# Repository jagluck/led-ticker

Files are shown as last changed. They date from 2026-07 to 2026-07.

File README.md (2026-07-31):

# LED Ticker

Desk sign + ambient ticker built on an ESP32-S3 and a 4-in-1 MAX7219 LED matrix. Rotates stocks, weather, news, and a clock; flips to a steady sign or a countdown timer on demand. Wi-Fi only feeds the live data; the sign and timer run fully offline.

<p align="center">
  <picture>
    <source media="(prefers-color-scheme: dark)" srcset="assets/device-sketch-dark.png">
    Line-art illustration of the LED Ticker — a 4-in-1 LED matrix in a bracket, wired to an ESP32-S3 board
  </picture>
</p>

## Features

- **Sign mode** — one-tap status text ("BUSY", "FOCUS", "DND") that overrides the ambient rotation, with an optional auto-clear timer. Or run a **countdown timer** (1–99 min): a live `MM:SS`, an end animation, then back to ambient.
- **Live data** — stock quotes (Finnhub), multi-location weather (MET Norway), and news.
- **12-hour clock** — steady `HH:MM` when shown alone, scrolls `H:MM AM/PM` when mixed in.
- **Display on/off** — blank the matrix and pause fetches without losing the saved ambient mode.
- **Adjustable brightness & scroll speed** — set from the mobile app or CLI, applied live and persisted on the device.
- **Companion mobile app** — multi-device switcher, preset chip grid, and per-category display toggles, on [iOS](https://apps.apple.com/app/id6772027776) and [Android](https://github.com/ssayala/led-ticker-android).
- **Configured entirely over BLE** — no build-time secrets; WiFi, Finnhub key, tickers, locations, mode, timezone, and active sign all set wirelessly and persisted.
- **PIN-gated BLE** — every write requires a 6-digit PIN, generated on first boot and rotated on factory reset.
- **Factory reset** — hold the BOOT button for 10 s to wipe all settings, forget every BLE bond, and reboot into setup mode with a fresh PIN.

## Hardware

A [Freenove ESP32-S3-WROOM (FNK0099)](https://store.freenove.com/products/fnk0099) and a 4-in-1 MAX7219 LED matrix (the common FC16 type, sold by many vendors). Wiring, porting notes, and pin config are in [Getting started](GETTING_STARTED.md#hardware--wiring). The repo includes a [custom PCB](hardware/pcb/README.md) and a [3D-printable frame](hardware/case/).

## Build & flash

1. Install [PlatformIO](https://platformio.org/).
2. Clone the repo: `git clone https://github.com/ssayala/led-ticker && cd led-ticker`.
3. Build and upload from the repo root: `pio run -d firmware -t upload`, then press the board's reset button.
4. First boot scrolls the BLE name + a 6-digit PIN — note it; you'll need it on every client.

No toolchain? Flash released firmware straight from a browser at **[ledticker.app/flash](https://ledticker.app/flash)**.

Provision from the mobile app or the CLI.

## Documentation

- **[Getting started](GETTING_STARTED.md)** — build, flash, first-boot pairing, and `config.h` tuning.
- **[Python client (`led_ticker`)](tools/README.md)** — `pip`-installable library (`from led_ticker import LedTicker`) and the `uv`-based `led.py` CLI, for driving the device or building your own tools.
- **[BLE protocol](BLE_PROTOCOL.md)** — UUIDs, payloads, and semantics for custom clients.
- **[Firmware guide](firmware/FIRMWARE_GUIDE.md)** — firmware internals: dual-core model, display state machine, and how to extend it.
- **[Custom PCB](hardware/pcb/README.md)** — board sources, render, and ordering.
- **[3D-printed frame](hardware/case/)** — printable parts (top/bottom strips or a single bracket) that hold the matrix and PCB together.
- **Companion mobile app** — [iOS](https://apps.apple.com/app/id6772027776) (App Store) and [Android](https://github.com/ssayala/led-ticker-android) (open source).

## License

Open and permissive — free to use, build, modify, share, and sell, including commercially, with attribution.

- **Firmware** — [Apache-2.0](LICENSE).
- **Hardware design files** in [`hardware/`](hardware/) (PCB, mechanical, frame STLs) — [CC BY 4.0](hardware/LICENSE).
- **Python client** in [`tools/`](tools/) (the `led_ticker` package & `led` CLI) — [Apache-2.0](tools/LICENSE).

Attribution is required by these licenses — please keep the credit; see [NOTICE](NOTICE).

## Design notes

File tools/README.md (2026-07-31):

# `led_ticker` — Python library & CLI for the LED Ticker

`led_ticker` speaks the same BLE service as the companion mobile app, so you can drive the
device — or build your own tools — from any machine with Bluetooth. The device
advertises as `LED-Ticker-XXXX`.

## Install

```bash
pip install led-ticker      # or: uv add led-ticker
```

This installs the importable `led_ticker` package and the `led` command.

## Running the CLI

How you invoke the CLI depends on how it was installed:

```bash
led <cmd>                   # pip install into an active venv → on PATH
uv run led <cmd>            # uv add led-ticker → script is in .venv/bin, not on PATH
uv run tools/led.py <cmd>   # from a checkout of this repo → uses ./src directly
```

The examples below use `led`; prefix with `uv run` if you installed via `uv add`.

## Library

```python
from led_ticker import LedTicker, scan

# Scan for available devices (returns DeviceInfo with name, address, rssi):
for d in scan():
    print(d.name, d.address, d.rssi)

# Reuse one connection for several operations:
with LedTicker(pin="482913") as d:
    d.set_tickers(["AAPL", "MSFT"])
    d.set_status("BUSY", minutes=30)
    print(d.get_version())          # -> "0.7.0"
    s = d.get_status()              # -> Status(text="BUSY", seconds=1800)

# Or a one-shot for a single call (opens and closes its own connection):
import led_ticker
led_ticker.set_mode(["stocks", "weather"])
```

`LedTicker(select=None, address=None, name_prefix="LED-Ticker", scan_timeout=4.0, timeout=15.0, pin=None)`.
By default the first `LED-Ticker-*` in range is used; if several are in range it raises
`AmbiguousDeviceError` (whose `.candidates` is a list of `DeviceInfo`). Pass `select=` to
choose a specific unit (see [Selecting a device](#selecting-a-device)), or `address=` to
target a known address directly (skips the scan). Methods raise
`ValidationError`, `AuthError`, `DeviceNotFoundError`, `AmbiguousDeviceError`, or
`ProtocolError` (all subclasses of `LedTickerError`).

`pin=None` does **not** mean "no auth" — it falls back to the same resolution the
CLI uses (`LED_TICKER_PIN` env var, then the `~/.config/led-ticker/pin` cache),
so a saved PIN is picked up automatically. Pass `pin="482913"` to override.

## Selecting a device

With more than one LED-Ticker in range, list them and target one explicitly:

```bash
led devices                 # list units: name, address, signal
led --device A1B2 status "BUSY" 30   # target by name suffix
```

`--device` matches a unit by its name suffix (the `XXXX` in `LED-Ticker-XXXX`),
its full name, or its Bluetooth address. If you run a command with several units
in range and no `--device`, an interactive terminal prompts you to choose; in a
script (no TTY) it lists the candidates and exits non-zero so you can re-run with
`--device`.

## CLI

```bash
# Sign mode
led status "BUSY" 30      # show for 30 min, then auto-clear
led status "ON AIR"       # indefinite
led status clear

# Timer mode (countdown sign — random animation at zero, then resumes ambient)
led timer 10              # 10-minute countdown
led timer cancel

# Ambient mode (subset of stocks/weather/news/clock, 'all', or 'none' for sign-only)
led mode stocks weather
led mode clock
led mode all
led mode none

# Power (volatile — power cycle returns to on)
led power on
led power off

# Display settings (persisted on the device)
led display                  # show current brightness + scroll speed
led display brightness 8     # brightness 0-15
led display speed 50         # scroll ms/step 20-500 (lower = faster)
led display 8 50             # both at once

# Timezone (persisted; POSIX TZ string — companion apps have a friendly picker)
led timezone                              # show current
led timezone "EST5EDT,M3.2.0,M11.1.0"     # US Eastern

# Data
led tickers AAPL TSLA NVDA SPY
led locations "47.61,-122.33,Seattle"   # lat,lon,label (look up coords online)
led apikey your-finnhub-key
led wifi My Network Name password

# Inspect
led get version           # firmware version on the device
led get wifi|apikey|tickers|status|locations|mode|power|display|timezone|version  # read other settings

# Auth
led pin 482913            # save the device's PIN locally (~/.config/led-ticker/pin)
led pin clear             # forget the saved PIN
led --pin 482913 status "BUSY" 30   # use a PIN for one call, without saving it
led pin-enforce on        # device: require PIN for writes (default after a fresh flash)
led pin-enforce off       # device: stop requiring PIN (escape hatch)

# Maintenance
led reload                # force stock/weather/news refresh
led reset                 # wipe NVS, rotate PIN, revert to config.h defaults
```

Save once, every platform: run `led pin <6 digits>` a single time and it's replayed on each connection automatically — no per-command `--pin`, on Linux, Windows, and macOS alike. (Companion mobile apps instead use OS-level Bluetooth *bonding* — the phone prompts for the PIN once and the OS remembers it; the CLI never bonds.)

PIN resolution: every command (and the library) looks for the PIN in this order — `--pin XXXXXX` flag → `LED_TICKER_PIN` env var → the saved cache file (`~/.config/led-ticker/pin`). The env var suits CI or anyone who'd rather not write the PIN to disk. If none is found and the device has enforcement on, writes fail with a clear `AuthError`.

Stale-PIN safety: every write probes the device after sending the PIN and exits with a clear error if the PIN was rotated by a factory reset — a write never fails silently because of an out-of-date local PIN.

## License

[Apache-2.0](LICENSE) — free to use, including commercially, with attribution. (The firmware in the parent repo is also Apache-2.0; the hardware design files are CC BY 4.0 — see the [repo root](https://github.com/ssayala/led-ticker).)

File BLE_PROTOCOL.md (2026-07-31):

# BLE Protocol

The device advertises as `LED-Ticker-XXXX`, where `XXXX` is the low 2 bytes of the chip MAC (so multiple boards on the same bench are distinguishable). All characteristics except `Command` are read/write — reads return current state. `Command` is write-only.

Writes are deferred: the BLE callback copies the payload and a main-loop pass applies it. Writes return immediately even when the change triggers network, display, or NVS work — clients should not assume the effect is observable synchronously.

## Service

`4fafc201-1fb5-459e-8fcc-c5c9c331914b`

## Characteristics

| Characteristic | UUID | Access |
|---|---|---|
| Tickers | `beb5483e-36e1-4688-b7f5-ea07361b26a8` | read/write |
| Mode | `beb5483e-36e1-4688-b7f5-ea07361b26a9` | read/write |
| Command | `beb5483e-36e1-4688-b7f5-ea07361b26ab` | write |
| WiFi | `beb5483e-36e1-4688-b7f5-ea07361b26ac` | read/write (read returns SSID only) |
| API Key | `beb5483e-36e1-4688-b7f5-ea07361b26ad` | read/write |
| Locations | `beb5483e-36e1-4688-b7f5-ea07361b26ae` | read/write |
| Status | `beb5483e-36e1-4688-b7f5-ea07361b26af` | read/write |
| Version | `beb5483e-36e1-4688-b7f5-ea07361b26b0` | read |
| Power | `beb5483e-36e1-4688-b7f5-ea07361b26b1` | read/write |
| Auth | `beb5483e-36e1-4688-b7f5-ea07361b26b2` | write |
| Display | `beb5483e-36e1-4688-b7f5-ea07361b26b3` | read/write |
| Timezone | `beb5483e-36e1-4688-b7f5-ea07361b26b4` | read/write |

UUID `...26aa` was once a "Messages" characteristic and is **not** registered in the current firmware. Reads against it fail at the GATT layer. Don't reuse the UUID.

## Payload formats

### Tickers
Comma-separated symbols. Example: `AAPL,MSFT,GOOGL`. Up to 10 symbols, 15 chars each.

### Mode
A single category (`stocks`, `weather`, `news`, `clock`), `all`, `none`, or a comma-separated subset (e.g. `stocks,weather`). Persisted to NVS. The device round-robins through enabled categories. When `clock` is the *only* enabled category the display shows a steady 24-hour `HH:MM`; mixed with others it scrolls the same `HH:MM`.

`none` is sign-only mode: no ambient rotation; between signs the display sits on the dim bouncing-pixel idle state. Reads return `"none"`.

Requesting a subset whose prereqs are missing (e.g. stocks without WiFi/API key) diverts the display to **setup mode** — the device scrolls its BLE name until the missing pieces are configured (or the 60s inactivity timer falls into the chosen mode).

The Status characteristic is **orthogonal** to the mode mask: an active sign overrides ambient until cleared or expired. When a sign clears on a device whose prereqs are still unmet, the display drops to **idle** (a single dim bouncing pixel) rather than the setup-name scroll — the user already found the device, so re-scrolling the name would be noise. Mode reads still return the configured mask; idle is an internal display state, not a settable mode.

### Status
Write `text|N` to set, empty payload to clear.

- `N` is unsigned integer *seconds* until auto-clear; `N=0` means indefinite (until cleared).
- Text up to 96 bytes. Short text (≤4 chars) displays steady; longer text scrolls.
- Reads return `text|M` where `M` is seconds remaining (`0` if indefinite), or empty string when no status is active.
- **RAM-only** — a power cycle clears any active sign and resumes ambient.
- Timed signs use the MCU's monotonic `millis()` counter, so they work without WiFi/NTP.
- There is no preset library on the device; preset chips are managed client-side (e.g. a companion app's local list).

### Locations
Pipe-separated `lat,lon,label` triplets — `47.61,-122.33,Seattle|47.67,-122.12,Redmond`. Up to 5 entries, 47 chars each. The **client** geocodes place names to coordinates — companion apps use the phone's location APIs; CLI users look up `lat`/`lon` themselves — so the device never contacts a geocoding service. `lat`/`lon` are decimal degrees; `label` is the text shown on the matrix (≤23 chars, may contain commas — only the first two commas are delimiters). Malformed or out-of-range entries are skipped.

### Command
Write-only.
- `reload` — force an immediate stock + weather + news fetch.
- `reset` — factory reset: wipe NVS and reboot. The wipe is deferred behind a 9-second single-digit countdown on the matrix (the BOOT-button hold shows the same digits) — **power-cycle the device during the countdown to abort**, since nothing is written until it finishes. Reverts to `config.h` defaults (clears WiFi, API key, any active sign, and the PIN — full reconfiguration needed after; a new PIN is generated and shown in setup mode). The connection drops when the device restarts; the write is ACKed first.
- `pin-enforce on` / `pin-enforce off` — toggle the Auth PIN gate on writes. **On is the default** on a fresh flash.
- `timer <minutes>` — countdown sign (1–99 whole minutes): live `MM:SS`, then a randomly-chosen end animation (fireworks / sonar pulse / sparkle), then ambient resumes. No cooldown — feels immediate, like a sign. Mutually exclusive with the text sign: each cancels the other. RAM-only and fire-and-forget — reads don't report timer state, so clients track the countdown locally.
- `timer cancel` — stop a running countdown and resume ambient immediately.

### WiFi
`SSID|password` — split on the first `|`. Passwords may contain `|`; SSIDs may not. Updates credentials, saves to NVS, reconnects immediately. Reads return the SSID only.

### API Key
Plain string — Finnhub API key. Saved to NVS, triggers an immediate stock fetch.

### Version
Read-only. Returns the firmware version (e.g. `0.1.0`) — the `FW_VERSION` define in `firmware/src/version.h`. Older firmwares won't expose this characteristic; treat its absence as "unknown / pre-0.1.0".

### Power
Write `"on"` or `"off"` (case-insensitive, whitespace-tolerant) to toggle the display. Reads return current state. Unknown payloads are ignored (no GATT error; state unchanged).

- Power is a third orthogonal layer alongside Mode and Status: `"off"` makes the device visually inert (matrix dark, NeoPixel dark, signs suppressed, periodic fetches paused — explicit-refresh writes like ticker updates or `reload` still apply) without touching `enabledMask` or any persisted state. `"on"` resumes the saved ambient mode and triggers an immediate fetch.
- Sign writes while off are accepted and stored but not rendered; on wake, an un-expired sign reappears. Timed signs keep counting down while off.
- **RAM-only — not persisted.** A power cycle returns the device to `"on"`. Older firmwares won't expose it.

### Display
Write `brightness|scroll_ms` — e.g. `4|70`. Brightness is the MAX7219 intensity, 0–15; scroll speed is ms per scroll step, 20–500 (lower = faster). Out-of-range values are clamped, non-numeric or separator-less payloads are ignored. Reads return current values in the same format.

- Persisted to NVS; survives reboot. Factory reset reverts both to the `config.h` defaults (brightness 2, scroll 70).
- Applied immediately — brightness everywhere, scroll speed including an in-flight scroll. Setup mode keeps its own fixed slower scroll until configuration completes.
- Older firmwares won't expose this characteristic.

### Timezone
Write a POSIX TZ string — e.g. `PST8PDT,M3.2.0,M11.1.0` (US Pacific) or `IST-5:30` (India). Up to 63 bytes; must start with a letter. Reads return the current string.

- Persisted to NVS; applied to the display clock immediately. Factory reset reverts to the `config.h` default (US Pacific).
- NYSE market hours are computed in Eastern Time from UTC, independent of this setting.
- Companion apps map a human-readable timezone picker to these strings; the raw format is only needed from the CLI.
- Older firmwares won't expose this characteristic.

### Auth

A BLE connection is "authenticated" (allowed to write to non-Auth characteristics) once either of these happens:

1. **Bonded link:** The device advertises passkey-entry pairing (`bond=true, MITM=true, SC=true`, IO cap `DISPLAY_ONLY`) and asks the central to pair on every fresh connection. The phone shows its native pairing dialog, and the user types the 6-digit PIN from the LED matrix.
2. **PIN write:** The client writes the 6-digit PIN to the Auth characteristic (`…26b2`, write-only). On match, the connection is authenticated for its lifetime. This is the fallback for clients that decline pairing (e.g., Python CLI on Linux).

Reads always work — auth gates writes only.

> [!NOTE]
> Implementation details regarding connection slots (`AuthSlot`), rate-limiting (5 wrong PINs → 5-second silent lockout), concurrent connection limits, and NVS PIN persistence can be found in the [Firmware Guide: Security & Auth](firmware/FIRMWARE_GUIDE.md#7-security-authentication--rate-limiting).

## Cooldown

Writes that trigger upstream network activity — Tickers, Locations, `Command=reload`, `Command=reset` — share a 10-second cooldown to prevent hammering the APIs if a client retries. Other writes (WiFi, API Key, Mode, Status, Power, Display, Timezone, Auth, `Command=pin-enforce`) are not gated.

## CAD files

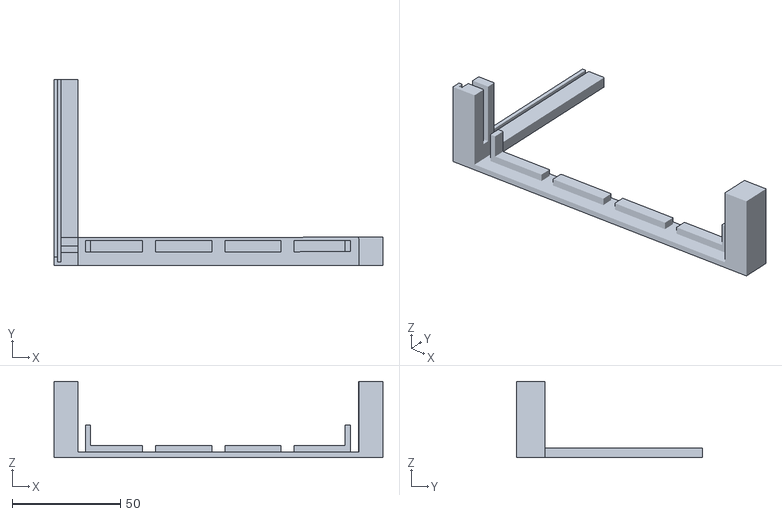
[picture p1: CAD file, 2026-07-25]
hardware/case/top-strip.stl
152.1 x 86.0 x 35.2

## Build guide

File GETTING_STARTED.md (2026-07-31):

# Getting started

Build, flash, and configure an LED Ticker. For what it is and what it does, see the [main README](README.md).

## Hardware & wiring

The firmware targets one specific board; the custom PCB is sized for the same module (see [`hardware/pcb/`](hardware/pcb/README.md)).

| Component | Part |
|---|---|
| MCU board | [**Freenove ESP32-S3-WROOM (FNK0099)**](https://store.freenove.com/products/fnk0099) — onboard NeoPixel on GPIO 48, native USB-CDC |
| Display | 4-in-1 MAX7219 LED matrix (FC16 type, any vendor) |

### Wiring (matches the PCB)

| Matrix Pin | ESP32-S3 GPIO |
|---|---|
| VCC | 5V |
| GND | GND |
| DIN | 6 (MOSI) |
| CLK | 4 (SCK) |
| CS | 5 |

Onboard RGB LED (GPIO 48) lights blue during network fetches. The Freenove board's **BOOT button (GPIO 0)** doubles as the factory-reset trigger — hold for 10 s during normal runtime.

**Using a different ESP32-S3 board?** Edit `DIN_PIN` / `CLK_PIN` / `CS_PIN` / `RGB_LED_PIN` in `firmware/src/config.h`. The PCB has no flexibility — it's footprint-specific to the FNK0099.

## Build & flash

1. Install [PlatformIO](https://platformio.org/).
2. Optionally edit defaults in `firmware/src/config.h` — seed tickers/locations (first-boot NVS seed) and the tunables under [Configuration](#configuration) below.
3. Build and upload from the repo root: `pio run -d firmware -t upload`. Press the physical reset button after flashing.
4. On first boot the display scrolls the BLE device name **and a 6-digit PIN** (e.g. `LED-Ticker-AB12  PIN 482 913`). Note the PIN — you'll need it on every client.

> **No toolchain?** Released firmware can be flashed straight from a browser over USB at **[ledticker.app/flash](https://ledticker.app/flash)** — Chrome or Edge on a desktop, no PlatformIO required.

## First-boot pairing

- **Phone app:** open the app, tap the device. The phone pops a system pairing dialog — type the PIN. Bonded. Future reconnects skip the dialog.
- **CLI:** save the PIN once; future calls auto-include it (see the [CLI tool](tools/README.md)):
  ```
  uv run tools/led.py pin 482913
  uv run tools/led.py wifi My Network Name password123
  uv run tools/led.py apikey your-finnhub-key
  ```
  The last arg to `wifi` is always the password — everything before it is the SSID, so spaces work naturally. To avoid saving the PIN to disk, pass `--pin 482913` per command or set `LED_TICKER_PIN=482913` in the environment instead.

If you ever forget the PIN, read it off the serial monitor (`pio device monitor -d firmware`) at boot, or factory-reset to rotate it.

## Configuration

**User tunables — `firmware/src/config.h`:**

| Define | Default | Description |
|---|---|---|
| `SCROLL_SPEED` | 70 | ms per scroll step (lower = faster) |
| `SETUP_SCROLL_SPEED` | 100 | Slower scroll used only in setup mode so the BLE name + PIN are easy to read. Reverts to `SCROLL_SPEED` once setup completes. |
| `DISPLAY_INTENSITY` | 2 | LED brightness, 0–15. Idle mode (post-sign with no ambient data) dims to 0 regardless of this setting. |
| `TIMEZONE` | `PST8PDT,M3.2.0,M11.1.0` | POSIX TZ string |
| `NTP_SERVER_1` / `NTP_SERVER_2` | `time.google.com` / `time.cloudflare.com` | NTP hosts (anycast, no vendor-zone registration) |
| `FETCH_INTERVAL_MS` | 5 min | Stock + weather + news refresh interval |

**Hardware pins — `firmware/src/config.h`:** `HARDWARE_TYPE`, `MAX_DEVICES` (4), `DIN_PIN`/`CLK_PIN`/`CS_PIN` (6/4/5), `RGB_LED_PIN` (48), `BUTTON_PIN` (0). Edit these when porting to a different board — see [Hardware & wiring](#hardware--wiring) above.

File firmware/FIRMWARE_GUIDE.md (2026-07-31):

# Firmware Guide

How the ESP32-S3 LED Ticker firmware works, at a high level. The detail lives in the code — `main.cpp` is structured and commented — and the Bluetooth wire format is in [`BLE_PROTOCOL.md`](../BLE_PROTOCOL.md). This is the map, not the territory.

## What it does

Drives a 4-panel LED matrix with two independent layers:

- **Ambient rotation** — cycles through whatever's enabled: stock quotes, weather, news, and a clock.
- **Override** — a text sign or a countdown timer that takes over the whole panel until it clears, then ambient resumes.

If it hasn't been configured yet (no WiFi or API key), it drops into a **setup** mode instead.

## Two cores

Network calls take seconds; the scrolling has to stay smooth. So the work is split across the ESP32's two cores:

- **Core 0** fetches data over WiFi and runs the Bluetooth stack.
- **Core 1** does everything you see — drives the matrix, runs the display modes, watches the button, and polls the USB serial console.

They hand off through shared buffers protected by a mutex. Control writes never draw or touch the network directly: a Bluetooth callback (Core 0) or the serial console poll (Core 1) just stashes the incoming value, and the Core 1 loop picks it up and applies it on its next pass. That keeps the radio and the display from stepping on each other.

```mermaid
graph TD
    subgraph Core0 ["Core 0 — network, async"]
        A[Fetch task] -->|HTTP, first| B1[Finnhub stocks]
        B1 -->|HTTP, then| B2[MET Norway weather]
        BLE[Bluetooth callback] -->|stash| Pend[Pending buffers]
    end
    subgraph Core1 ["Core 1 — one loop pass, top to bottom"]
        direction TB
        Ser[Poll serial console] --> Apply[Apply pending]
        Apply --> Btn[Poll boot button]
        Btn --> Draw[Draw LED matrix]
        Draw -.->|next pass| Ser
    end
    Ser -->|stash| Pend
    Pend -->|read| Apply
    B1 & B2 -.->|guarded by mutex| Draw
```

## Display modes

Three top-level modes, plus the override layer on top.

```mermaid
stateDiagram-v2
    [*] --> Setup : not configured
    [*] --> Idle : nothing enabled
    [*] --> Content : configured & enabled
    Setup --> Content : config arrives
    Content --> Idle : everything turned off
    Idle --> Content : a category turned on
```

- **Setup** — not yet usable. Scrolls its Bluetooth name (`LED-Ticker-XXXX`) so you can find it in the app and configure it.
- **Content** — the normal state. Rotates through the enabled categories, skipping any that have no data yet.
- **Idle** — sign-only. Nothing in the rotation, so a single pixel bounces around the panel to show it's alive.

**The override layer** sits above all three. A text sign (short text holds steady; longer text scrolls) or a countdown timer takes over the panel. The timer counts down `MM:SS` and finishes with a brief explosion animation before ambient resumes. The two overrides are mutually exclusive — starting one cancels the other.

When several things want the screen at once, this is the priority order: a factory-reset countdown wins over everything, then power-off (blank), then the timer, then a text sign, then the normal idle/ambient rotation.

## How it's controlled

**Bluetooth is the real control plane** — the companion app talks to it, and that contract (the protocol) is what lets the app evolve without firmware changes. A **USB serial console** mirrors every command; it's there for development and is the only way to drive the device in the Wokwi simulator, where Bluetooth isn't available.

Configuration writes are PIN-gated. The PIN shows on the panel during setup and prints to serial at every boot.

What's saved and what isn't: configuration (WiFi, keys, tickers, locations, brightness, timezone, PIN) persists in flash. Fetched quotes/weather/news and the active sign are **RAM-only** — a power cycle throws them away and comes back to a clean ambient rotation.

## Where the data comes from

Every few minutes Core 0 refreshes stock quotes (Finnhub), weather (MET Norway), and news, and the clock syncs from NTP. A couple of things worth knowing:

- Stocks only fetch during US market hours; off-hours it keeps showing the last prices.
- The device doesn't look up locations itself — the app resolves a place name to coordinates and sends those, so the firmware stays simple and keyless for weather.

## Resetting

A factory reset wipes all configuration, forgets paired devices, rotates the PIN, and reboots into setup. Two ways to trigger it — hold the BOOT button for 10 seconds, or send a reset command from the app. Both show a visible countdown you can abort first (release the button, or power-cycle the device).

## If you're editing the firmware

A handful of non-obvious invariants the code depends on — break these and things misbehave in confusing ways:

- **The main loop is cooperative.** Never `delay()` in the middle of it; animations are timed off `millis()` instead, so nothing blocks the scrolling or the radio.
- **Only Core 1 touches the status LED.** Driving it from the fetch task can lock up the LED driver.
- **Don't start the clock (NTP) before WiFi connects** — it wedges the device.
- **Text handed to the display must outlive the call.** The matrix library keeps the pointer you give it, not a copy, so use a static/global buffer, never a local one.
- **Pick the right font face.** Everything steady — text, signs, clock, timer — uses the Press Start 2P static face (`useStaticFont`); scrolling uses the thin system font (`useScrollFont`). Press Start 2P's digits are hand-condensed to 6px (in `tools/gen_pressstart_font.py`) so a five-glyph time (clock `HH:MM`, timer `MM:SS`) fits the 32-col panel — the original 7px digits would overflow. `bold_font.h` stays compiled as a future BLE-selectable second face. Faces are generated by `tools/gen_pressstart_font.py` / `tools/gen_bold_font.py`.

Everything else — exact pin assignments, NVS keys, characteristic UUIDs, the fetch and render functions — is in the source and in [`BLE_PROTOCOL.md`](../BLE_PROTOCOL.md). Read those for specifics; this guide is just the shape of things.

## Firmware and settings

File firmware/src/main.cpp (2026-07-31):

#include <Arduino.h>
#include <ArduinoJson.h>
#include <HTTPClient.h>
#include <MD_MAX72xx.h>
#include <MD_Parola.h>
#include <NimBLEDevice.h>
#include <Preferences.h>
#include <SPI.h>
#include <WiFi.h>
#include <WiFiClientSecure.h>
#include <time.h>

#include "bold_font.h"
#include "config.h"
#include "console.h"
#include "logic.h"
#include "pressstart_font.h"
#include "version.h"

// ============================================================================
// File map — read setup() and loop() (bottom, under "Main") first; they are the
// entry points. Everything above them is the units they orchestrate, ordered so
// each definition precedes its first use (C++ requirement, hence entry-points-
// last). Top to bottom:
//
//   Mode bits & hardware constants  — display layers, pins
//   Forward decls                   — the few vars defined out of order
//   NVS: <wifi|apikey|pin|tickers|locations|mask|display|timezone>
//                                   — persisted config; each a save*/load* pair
//   Setup- & active-status state    — RAM-only display state
//   Display / Status LED / Time     — matrix, NeoPixel, NTP + market hours
//   Network fetch                   — Core-0 task hitting Finnhub / MET Norway
//   WiFi connect
//   Display rotation & rendering    — showNext() and the per-mode tick*() drawers
//   BLE                             — characteristics + deferred applyPending*()
//   Main                            — pollResetButton, setup(), console, loop()
//
// Pure, host-tested helpers live in logic.{h,cpp}, not here.
// ============================================================================

// ============================================================================
// Mode bits
// ============================================================================
// An active status sign overrides both modes until expiry/clear.
// 0x02 was once BIT_MESSAGES — tombstoned; legacy NVS masks are stripped
// via `& MASK_ALL` on load. When BIT_CLOCK is the only enabled bit, the
// display switches to a steady non-scrolling clock — see tickStaticClock().

enum {
  MODE_CONTENT,
  MODE_SETUP,
  MODE_IDLE,
};

// The category bits (BIT_STOCKS/WEATHER/CLOCK), MASK_ALL, and the
// MASK_NONE_REQUEST parser sentinel live in logic.h — host-tested alongside
// parseModePayload().

// ============================================================================
// Hardware & display constants
// ============================================================================
// Pins, MAX_DEVICES, and HARDWARE_TYPE are the porting knobs — they live in
// config.h. HARDWARE_TYPE references MD_MAX72XX, which is in scope here
// because this file includes MD_MAX72xx.h above config.h's use site.

// Factory-reset hold timings. GPIO0 (BOOT) is only sampled at reset, so
// runtime polling is safe — but holding it while pressing RESET drops the
// chip into the ROM bootloader instead.
#define RESET_HOLD_MS 10000
#define RESET_HINT_AT_MS 2000
// Remote (BLE/console) reset shows a single-digit countdown before wiping, so
// the user can power-cycle to abort. 9 s ≈ the button's visible window; single
// digit because "10" won't fit the 32 px matrix.
#define RESET_COUNTDOWN_SECS 9

// Scroll buffer cell size. Also bounds STATUS_MAX_LEN.
#define MAX_STRING_LEN 96

// ============================================================================
// Forward decls of vars defined further down (so order-of-definition can
// follow the logical narrative rather than strict topological order).
// ============================================================================

// Defined in the BLE section; consumed earlier by showNextSetup().
extern char bleDeviceName[24];

// ============================================================================
// Preferences (NVS) — single shared instance, used on Core 1 only
// ============================================================================

Preferences prefs;

// Shared persistence for the string lists (tickers, locations): a "count"
// int plus indexed entries ("t0", … / "l0", …). `list` is a flat buffer
// with entry stride `entryLen`. Load seeds from defaults when NVS is empty
// or out of range, and returns the resulting count.

static void saveStringListToNVS(const char* ns, const char* keyPrefix, const char* list,
                                int entryLen, int count) {
  prefs.begin(ns, false);
  prefs.putInt("count", count);
  for (int i = 0; i < count; i++) {
    char key[8];
    snprintf(key, sizeof(key), "%s%d", keyPrefix, i);
    prefs.putString(key, list + i * entryLen);
  }
  prefs.end();
}

static int loadStringListFromNVS(const char* ns, const char* keyPrefix, char* list, int entryLen,
                                 int maxCount, const char* const* defaults, int defaultCount,
                                 const char* what) {
  prefs.begin(ns, true);
  int count = prefs.getInt("count", 0);
  if (count > 0 && count <= maxCount) {
    for (int i = 0; i < count; i++) {
      char key[8];
      snprintf(key, sizeof(key), "%s%d", keyPrefix, i);
      prefs.getString(key, list + i * entryLen, entryLen);
    }
    prefs.end();
    Serial.printf("Loaded %d %s from NVS\r\n", count, what);
    return count;
  }
  prefs.end();
  int seeded = defaultCount < maxCount ? defaultCount : maxCount;
  for (int i = 0; i < seeded; i++) {
    strncpy(list + i * entryLen, defaults[i], entryLen - 1);
    list[(i + 1) * entryLen - 1] = '\0';
  }
  saveStringListToNVS(ns, keyPrefix, list, entryLen, seeded);
  Serial.printf("Seeded %d %s from defaults\r\n", seeded, what);
  return seeded;
}

// ============================================================================
// NVS: WiFi credentials
// ============================================================================

#define WIFI_SSID_MAX 64
#define WIFI_PASS_MAX 64

char nvsWifiSsid[WIFI_SSID_MAX];
char nvsWifiPass[WIFI_PASS_MAX];

void saveWifiToNVS() {
  prefs.begin("wifi", false);
  prefs.putString("ssid", nvsWifiSsid);
  prefs.putString("pass", nvsWifiPass);
  prefs.end();
}

void loadWifiFromNVS() {
  prefs.begin("wifi", true);
  bool hasSsid = prefs.isKey("ssid");
  if (hasSsid) {
    prefs.getString("ssid", nvsWifiSsid, WIFI_SSID_MAX);
    prefs.getString("pass", nvsWifiPass, WIFI_PASS_MAX);
    Serial.printf("Loaded WiFi credentials from NVS (SSID: %s)\r\n", nvsWifiSsid);
  } else {
    nvsWifiSsid[0] = '\0';
    nvsWifiPass[0] = '\0';
    Serial.println("WiFi not configured — use BLE to set credentials");
  }
  prefs.end();
}

bool wifiConfigured() { return nvsWifiSsid[0] != '\0'; }

// ============================================================================
// NVS: Finnhub API key
// ============================================================================

#define MAX_APIKEY_LEN 64

char nvsApiKey[MAX_APIKEY_LEN];

void saveApiKeyToNVS() {
  prefs.begin("apikey", false);
  prefs.putString("key", nvsApiKey);
  prefs.end();
}

void loadApiKeyFromNVS() {
  prefs.begin("apikey", true);
  bool hasKey = prefs.isKey("key");
  if (hasKey) {
    prefs.getString("key", nvsApiKey, MAX_APIKEY_LEN);
    Serial.println("Loaded API key from NVS");
  } else {
    nvsApiKey[0] = '\0';
    Serial.println("Finnhub API key not configured — use BLE to set it");
  }
  prefs.end();
}

bool apiKeyConfigured() { return nvsApiKey[0] != '\0'; }

// ============================================================================
// NVS: BLE auth PIN
// ============================================================================
// 6-digit PIN gating writes while nvsPinEnforce is on (default). Recovery
// channels: MODE_SETUP scroll and serial at boot. `pin-enforce off` is the
// unauthenticated escape hatch.

#define PIN_LEN 6

char nvsPin[PIN_LEN + 1] = {0};
bool nvsPinEnforce = true;

void savePinToNVS() {
  prefs.begin("pin", false);
  prefs.putString("code", nvsPin);
  prefs.putBool("on", nvsPinEnforce);
  prefs.end();
}

// Persist only the enforce flag — used by `pin-enforce on/off` so toggling
// the gate doesn't rewrite the unchanged 6-byte PIN string back to flash.
void savePinEnforceToNVS() {
  prefs.begin("pin", false);
  prefs.putBool("on", nvsPinEnforce);
  prefs.end();
}

static void generateAndSavePin() {
  uint32_t n = esp_random() % 1000000UL;
  snprintf(nvsPin, sizeof(nvsPin), "%06lu", (unsigned long)n);
  savePinToNVS();
  Serial.printf("Generated new BLE auth PIN: %s\r\n", nvsPin);
}

void loadPinFromNVS() {
  prefs.begin("pin", true);
  bool hasCode = prefs.isKey("code");
  if (hasCode) {
    prefs.getString("code", nvsPin, sizeof(nvsPin));
    // Default to enforcing if the "on" key was never written (e.g. namespace
    // existed from an earlier build that only stored "code").
    nvsPinEnforce = prefs.getBool("on", true);
    Serial.printf("Loaded BLE auth PIN from NVS: %s (enforce=%d)\r\n", nvsPin, nvsPinEnforce);
  } else {
    nvsPin[0] = '\0';
    nvsPinEnforce = true;
  }
  prefs.end();
}

// Separate from loadPinFromNVS so callers can defer until after initBLE():
// esp_random() has no HW entropy until the RF subsystem is up, and a PIN
// generated before that is predictable.
void ensurePinExists() {
  if (nvsPin[0]) return;
  generateAndSavePin();
}

// ============================================================================
// NVS: Stock tickers + in-RAM quote state
// ============================================================================

#define MAX_STOCKS 10
#define MAX_TICKER_LEN 16

char nvsTickers[MAX_STOCKS][MAX_TICKER_LEN];
int nvsTickerCount = 0;

struct StockQuote {
  char symbol[MAX_TICKER_LEN];
  float price;
  float changePct;
};

StockQuote stockQuotes[MAX_STOCKS];
int stockCount = 0;
int currentStock = 0;

void saveTickersToNVS() {
  saveStringListToNVS("tickers", "t", &nvsTickers[0][0], MAX_TICKER_LEN, nvsTickerCount);
}

void loadTickersFromNVS() {
  nvsTickerCount = loadStringListFromNVS("tickers", "t", &nvsTickers[0][0], MAX_TICKER_LEN,
                                         MAX_STOCKS, stockTickers, stockTickerCount, "tickers");
}

// ============================================================================
// NVS: Weather locations + in-RAM resolution & readings
// ============================================================================

#define MAX_LOCATIONS 5
#define MAX_NEWS 20
// MAX_LOCATION_LEN, MAX_LOC_NAME_LEN, the ResolvedLocation struct, and
// parseLocation() live in logic.h/.cpp (host-tested).

char nvsLocations[MAX_LOCATIONS][MAX_LOCATION_LEN];
int nvsLocationCount = 0;

ResolvedLocation resolved[MAX_LOCATIONS];

// Re-derives resolved[] from the stored location strings. Call after locations
// load or change — cheap, no network.
static void reparseLocations() {
  for (int i = 0; i < MAX_LOCATIONS; i++) {
    resolved[i].ok = false;
    if (i < nvsLocationCount) parseLocation(nvsLocations[i], resolved[i]);
  }
}

struct WeatherReading {
  char name[MAX_LOC_NAME_LEN];
  float tempF;
};

WeatherReading weatherReadings[MAX_LOCATIONS];
int weatherCount = 0;
int currentWeather = 0;

#define MAX_NEWS_LEN 96
struct NewsReading {
  char name[MAX_LOC_NAME_LEN];
  char text[MAX_NEWS_LEN];
};

NewsReading newsReadings[MAX_NEWS];
int newsCount = 0;
int currentNews = 0;
static bool awaitingNewsPause = false;
static uint32_t newsPauseEnd = 0;

void saveLocationsToNVS() {
  saveStringListToNVS("locs", "l", &nvsLocations[0][0], MAX_LOCATION_LEN, nvsLocationCount);
}

void loadLocationsFromNVS() {
  nvsLocationCount =
      loadStringListFromNVS("locs", "l", &nvsLocations[0][0], MAX_LOCATION_LEN, MAX_LOCATIONS,
                            defaultLocations, defaultLocationCount, "locations");
  reparseLocations();
}

// ============================================================================
// NVS: Enabled-category mask
// ============================================================================

uint8_t enabledMask = MASK_ALL;

void saveDisplayMaskToNVS() {
  prefs.begin("display", false);
  prefs.putUChar("mask", enabledMask);
  prefs.end();
}

void loadDisplayMaskFromNVS() {
  prefs.begin("display", true);
  if (prefs.isKey("mask")) {
    // mask=0 is now a valid persisted value ("none" mode — sign-only with
    // idle pixel between signs), so don't fall back to MASK_ALL here.
    enabledMask = prefs.getUChar("mask", MASK_ALL) & MASK_ALL;
  }
  prefs.end();
  Serial.printf("Display mask: 0x%02X\r\n", enabledMask);
}

// ============================================================================
// NVS: Display settings (brightness + scroll speed)
// ============================================================================
// BLE-settable (Display characteristic); clamped at the apply step, so NVS
// only ever holds valid values. Shares the "display" namespace with the mask.

uint8_t displayBrightness = DISPLAY_INTENSITY;
uint16_t scrollSpeedMs = SCROLL_SPEED;

void saveDisplaySettingsToNVS() {
  prefs.begin("display", false);
  prefs.putUChar("bright", displayBrightness);
  prefs.putUShort("scroll", scrollSpeedMs);
  prefs.end();
}

void loadDisplaySettingsFromNVS() {
  prefs.begin("display", true);
  displayBrightness = prefs.getUChar("bright", DISPLAY_INTENSITY);
  scrollSpeedMs = prefs.getUShort("scroll", SCROLL_SPEED);
  prefs.end();
  Serial.printf("Display settings: brightness=%u scroll=%ums\r\n", displayBrightness,
                (unsigned)scrollSpeedMs);
}

// ============================================================================
// NVS: Timezone
// ============================================================================
// POSIX TZ string for the display clock; BLE-settable (Timezone
// characteristic), config.h TIMEZONE is the fresh-flash default. Market
// hours are computed in ET from UTC and don't depend on this.

#define MAX_TZ_LEN 64

char nvsTimezone[MAX_TZ_LEN] = TIMEZONE;

void saveTimezoneToNVS() {
  prefs.begin("time", false);
  prefs.putString("tz", nvsTimezone);
  prefs.end();
}

void loadTimezoneFromNVS() {
  prefs.begin("time", true);
  if (prefs.isKey("tz")) {
    prefs.getString("tz", nvsTimezone, MAX_TZ_LEN);
  }
  prefs.end();
  Serial.printf("Timezone: %s\r\n", nvsTimezone);
}

// ============================================================================
// Setup-mode state
// ============================================================================
// Unmet prereqs drop the display into MODE_SETUP, scrolling the BLE device
// name on a loop. `setupTargetMask` records what to resume into once
// prereqs are met (or after the inactivity timeout).

#define SETUP_TIMEOUT_MS 60000

volatile unsigned long setupLastActivityMs = 0;
uint8_t setupTargetMask = MASK_ALL;

// ============================================================================
// Active-status state (sign mode)
// ============================================================================
// Sign-mode override: a non-empty, unexpired activeStatusText renders in
// place of ambient. statusExpiresAt is a millis() target (not epoch — works
// without NTP); 0 = none, UINT32_MAX = indefinite. Wrap-safe via signed
// delta in checkStatusForRender. RAM-only — power cycle clears the sign.

// ≤4 chars renders static, longer scrolls. Cutoff is 4 not 5 because the panel's
// bold font is wider — 5 wide bold chars overflow 32 cols. See tickActiveStatus()
// and firmware/src/bold_font.h.
#define STATUS_MAX_LEN MAX_STRING_LEN
#define STATUS_STATIC_MAX_CHARS 4

char activeStatusText[STATUS_MAX_LEN] = {0};
uint32_t statusExpiresAt = 0;

void clearStatus() {
  activeStatusText[0] = '\0';
  statusExpiresAt = 0;
}

// ============================================================================
// Display
// ============================================================================

MD_Parola display = MD_Parola(HARDWARE_TYPE, CS_PIN, MAX_DEVICES);

// MD_Parola stores the pointer passed to displayScroll, not a copy.
// Shared across all scrolling content (stocks/weather/news/clock/status/setup) —
// only one is ever active, and we overwrite only when starting the next scroll.
static char scrollBuf[MAX_STRING_LEN + 1];

// The panel uses two faces:
//   - staticFace — Press Start 2P (pressstart_font.h) — for everything steady:
//     text, signs, clock, timer, setup. a-z fold onto A-Z, so it renders
//     all-caps (PS2P's lowercase has descenders that don't fit 8 rows). Its
//     digits are hand-condensed to 6px (see gen_pressstart_font.py) so a
//     five-glyph time (clock HH:MM, timer MM:SS) fits the 32-col panel; the
//     original 7px digits would overflow or squish.
//   - the built-in system font for anything that scrolls — heavier faces ghost
//     in motion, and the thin stock font stays crisp at a fast scroll.
//     setFont(nullptr) selects _sysfont (MD_MAX72xx_font.cpp), plain mixed-case.
// setFont only takes effect at the next text parse (displayText/displayScroll or
// a displayReset re-parse). Static sites assert the static face right before
// rendering; every scroll routes through scrollTextAt(), so the scroll face is
// structural rather than remembered per site. const_cast is safe: setFont only
// reads the table (pgm_read_byte).
//
// bold_font.h stays compiled as a second, non-default face so a future BLE
// font-select verb has something to switch to; staticFace is the single point
// it would flip (read an NVS key, reassign, re-parse). Today it's a constant.
static const MD_MAX72XX::fontType_t* staticFace = PRESSSTART_FONT;
static void useStaticFont() { display.setFont(const_cast<MD_MAX72XX::fontType_t*>(staticFace)); }
static void useScrollFont() {
  display.setFont(nullptr);  // built-in system font
}

// Steady clock/timer render. The static face's condensed digits fit a five-glyph
// time on the panel. The caller clears first if it needs to (the clock does; the
// timer overwrites in place).
static void renderSteadyNumber(const char* buf) {
  useStaticFont();
  display.displayText(buf, PA_CENTER, 0, 0, PA_PRINT, PA_NO_EFFECT);
  display.displayAnimate();
}

void initDisplay() {
  SPI.begin(CLK_PIN, -1, DIN_PIN, CS_PIN);
  display.begin();
  useStaticFont();  // a face must be set before first render; call sites reassert
  display.setIntensity(displayBrightness);
  display.displayClear();
}

// The one scroll primitive — every scrolling path routes here, so the thin
// scroll face is set in a single place. scrollText() uses the user's configured
// speed; callers that need a different speed (setup) pass it explicitly.
//
// The stock scroll font has real lowercase glyphs, but the panel's identity is
// all-caps (the static face folds a-z onto A-Z), so we fold here too — keeping
// the case uniform between static and scrolling content whatever the input. The
// uppercased copy lands in scrollBuf because MD_Parola keeps the pointer, not a
// copy, so it must outlive the scroll; a self-copy (callers passing scrollBuf)
// is safe since dst and src index in lockstep. Only ASCII a-z folds — the
// degree symbol and arrows (high-bit bytes) pass through untouched.
void scrollTextAt(const char* msg, uint16_t speedMs, bool preserveCase = false) {
  size_t i = 0;
  for (; msg[i] && i < sizeof(scrollBuf) - 1; i++) {
    char c = msg[i];
    scrollBuf[i] = (!preserveCase && c >= 'a' && c <= 'z') ? c - 'a' + 'A' : c;
  }
  scrollBuf[i] = '\0';
  useScrollFont();
  display.displayScroll(scrollBuf, PA_LEFT, PA_SCROLL_LEFT, speedMs);
}

void scrollText(const char* msg) { scrollTextAt(msg, scrollSpeedMs); }

// ============================================================================
// Status LED (onboard NeoPixel)
// ============================================================================
// Lit blue during network fetches. Driven from loop() via a volatile flag
// set by the fetch task on Core 0 — neopixelWrite from another core hangs.

volatile bool fetching = false;
static bool ledState = false;
// Display power: when true, suppress all rendering and force the NeoPixel
// dark. RAM-only; set via the Power BLE characteristic in the section
// further down. Lives up here so updateStatusLed() (just below) can read it.
static bool displayOff = false;

void updateStatusLed() {
  if (displayOff) {
    if (ledState) {
      neopixelWrite(RGB_LED_PIN, 0, 0, 0);
      ledState = false;
    }
    return;
  }
  if (fetching && !ledState) {
    neopixelWrite(RGB_LED_PIN, 0, 0, 20);
    ledState = true;
  } else if (!fetching && ledState) {
    neopixelWrite(RGB_LED_PIN, 0, 0, 0);
    ledState = false;
  }
}

// ============================================================================
// Time / Market hours
// ============================================================================

bool timeReady = false;
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
void loop() {
  heartbeat(millis());

  pollSerialConsole();  // serial console feeds the same pending* flags
  applyPendingUpdates();

  updateStatusLed();
  if (pollResetButton() || tickResetCountdown()) {
    // A reset countdown (button hold or remote command) owns the display this
    // tick — skip the renderers.
    delay(1);
    return;
  }

  if (currentMode == MODE_SETUP && millis() - setupLastActivityMs > SETUP_TIMEOUT_MS) {
    if (wifiConfigured()) {
      Serial.println("Setup: 60s no activity, falling to content (mask unchanged)");
      enterContent();
    } else {
      // No WiFi → every category is dead; staying on the name scroll beats
      // a "Loading X..." loop. Reschedule the timeout check.
      setupLastActivityMs = millis();
    }
  }

  if (displayOff) {
    // Display is off: skip all render AND fetch work.
    delay(100);
    return;
  }

  renderActiveFrame();

  if (millis() - lastFetch > FETCH_INTERVAL_MS) {
    lastFetch = millis();
    triggerFetch();
  }

  // Yield one tick once this iteration's work is done — lets Core 1 idle (WAITI)
  // instead of busy-spinning at 240 MHz. ~1 kHz loop rate is ample for scroll
  // timing and BLE; cuts idle power/heat. Pacing only — never delay() mid-work.
  delay(1);
}

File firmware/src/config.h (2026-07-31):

#pragma once

// Default stock symbols — used to seed NVS on first boot.
// After that, update them via BLE: uv run tools/led.py tickers AAPL MSFT ...
const char* stockTickers[] = {"AAPL", "GOOG", "MSFT", "AMZN"};
const int stockTickerCount = sizeof(stockTickers) / sizeof(stockTickers[0]);

// Default weather locations — "lat,lon,label" triplets. The client geocodes;
// the device never resolves place names itself. Used to seed NVS on first boot.
// After that, update them via BLE: uv run tools/led.py locations
// "47.61,-122.33,Seattle" ...
const char* defaultLocations[] = {"47.67,-122.12,Redmond",
                                  "47.61,-122.33,Seattle"};
const int defaultLocationCount =
    sizeof(defaultLocations) / sizeof(defaultLocations[0]);

// Serial command console. Off on real hardware (USB serial is an unauthenticated
// control path); the wokwi env leaves it on since BLE isn't simulated there and
// it's the only way to drive the sim. Override per-env via build_flags.
#ifndef CONSOLE_ENABLED
#define CONSOLE_ENABLED 1
#endif

#define HARDWARE_TYPE MD_MAX72XX::FC16_HW  // real DIYables 4-in-1 panel
#define MAX_DEVICES 4
#define DIN_PIN 6  // MOSI USE 23 FOR esp32dev
#define CLK_PIN 4  // SCK USE 18 FOR esp32dev
#define CS_PIN 5
#define RGB_LED_PIN 48  // Freenove onboard WS2812
// Factory-reset button. BOOT button on most ESP32-S3 devkits is GPIO 0.
// GPIO0 is sampled by the bootloader only at hardware-reset time, so polling
// it at runtime is safe. (Hold timings live in main.cpp — they're behavior,
// not a porting knob.)
#define BUTTON_PIN 0

// --- Display behavior ---
// SCROLL_SPEED and DISPLAY_INTENSITY are fresh-flash defaults only — both
// are BLE-settable (Display characteristic) and persisted to NVS.
#define SCROLL_SPEED 70  // ms per scroll step (lower = faster)
// Slower setup-mode scroll so the device name + PIN are readable while
// pairing. Not user-settable.
#define SETUP_SCROLL_SPEED 100
#define DISPLAY_INTENSITY 2  // 0–15

// --- Timer mode (countdown sign) ---
// Whole-minute countdown rendered as MM:SS, then the end-of-timer animation.
#define TIMER_MAX_MINUTES 99
// End animation (non-blocking, frame-stepped like the idle pixel): a single
// looped "explosion" — a detonation flash, an expanding thick shockwave, and
// diagonal debris rays — fired repeatedly from center until the run ends.
#define ANIM_FRAME_MS 80                         // ms per animation frame
#define ANIM_CENTER_COL ((8 * MAX_DEVICES) / 2)  // 16 on a 4-module matrix
#define ANIM_CENTER_ROW 3
#define EXPLOSION_FRAMES 60          // total frames (~4.8 s at ANIM_FRAME_MS)
#define EXPLOSION_CADENCE 6          // frames between successive detonations
#define EXPLOSION_MAX_R 20           // shockwave radius that clears the matrix
#define EXPLOSION_FLASH_INTENSITY 8  // panel brightness pop on each detonation
// Blank pause after the last explosion frame before ambient resumes — a
// hard cut reads as a glitch.
#define EXPLOSION_END_HOLD_MS 1000

// --- Time / NTP ---
// Default POSIX TZ string for the display clock — BLE-settable (Timezone
// characteristic) and persisted to NVS. Market hours are computed in ET
// from UTC regardless of this setting.
#define TIMEZONE "PST8PDT,M3.2.0,M11.1.0"
// Anycast public NTP — no vendor-zone registration (unlike pool.ntp.org) and
// no per-fleet obligation. Google primary smears leap seconds (no 23:59:60).
#define NTP_SERVER_1 "time.google.com"
#define NTP_SERVER_2 "time.cloudflare.com"

#define NEWS_PAUSE_MS 3000

// How often loop() triggers a stocks+weather fetch (5 minutes by default).
#define FETCH_INTERVAL_MS (5 * 60 * 1000)

// Weather changes slowly upstream — throttle it apart from the stock cadence
// so it only hits the API every 30 minutes, not on every fetch tick.
#define WEATHER_INTERVAL_MS (30 * 60 * 1000)

// MET Norway (api.met.no) requires an identifying User-Agent with contact info
// or it returns 403 for new clients. Set this to your project/contact.
#define WEATHER_USER_AGENT \
  "LED-Ticker (https://github.com/ssayala/led-ticker)"

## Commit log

2026-07-03 feat(firmware): tabular digits for steady numbers, bump to 0.8.1
    Pad every digit (centered) to a uniform width in gen_bold_font.py so the
    clock, timer and prices don't re-center when a 1 ticks in or out. Scroll
    face is unchanged (jitter is a non-issue on moving text).
2026-07-03 feat(firmware): Press Start 2P static panel face, bump to 0.9.0
    Render all steady content (text, signs, clock, timer, setup) in Press Start
    2P instead of the emboldened bold face.
    - Generate a pixel-faithful table from the OFL TTF: tools/gen_pressstart_font.py
    rasterizes the font on its native 8-row grid (block-majority, pen-anchored
    sampling) into firmware/src/pressstart_font.h. Folds a-z onto A-Z (all-caps)
    and falls back to the bold glyph for codes PS2P lacks, so it's a drop-in over
    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
2026-07-04 fix(firmware): unique BLE name suffix from NIC MAC bytes, bump to 0.9.1
    getEfuseMac() returns the MAC byte-reversed, so the old low-two-byte
    suffix was the shared Espressix OUI — every unit in a batch collided
    on the same name (e.g. LED-Ticker-A994). Derive the suffix from the
    top two bytes (mac[5], mac[4], the per-device NIC portion) so each
    unit advertises a distinct LED-Ticker-XXXX regardless of lot.
    [main.cpp]
2026-07-05 docs(tools): fix PyPI README to use the installed 'led' command
    The published README used 'uv run tools/led.py' throughout, a checkout-only
    path that doesn't exist for a pip/uv install. Switch all CLI examples to the
    'led' command and add a 'Running the CLI' section covering the three
    invocations (led, uv run led, uv run tools/led.py). Bump led-ticker 0.3.0 -> 0.3.1.
2026-07-10 added top fram mods and readme change
    [top-strip.stl]
2026-07-13 fix(firmware): repaint steady clock immediately on resume from sign, bump to 0.9.2
    Clearing a sign (or its expiry, or a timer ending) in clock-only mode
    blanked the panel via resetDisplay() but left staticClockLastMin holding
    the prior minute, so tickStaticClock()'s repaint guard suppressed the
    redraw until the next minute rollover (up to ~60s dark). Reset the cache
    in resumeAmbient() so the clock repaints on the next frame, mirroring the
    existing timezone-change reset.
    [main.cpp]
2026-07-16 fix(firmware): drop static-sign breathing, hold steady brightness, bump to 0.9.3
    The MAX7219's 16 intensity levels can't render a smooth breathe at the
    brightness people actually run. At the default intensity of 2 the dip
    clamps to 0, so the sign read as a hard blink rather than a pulse.
    Remove the breath state machine and the SIGN_BREATH_* constants; static
    signs now hold steady at the configured brightness.
    [config.h, main.cpp]
2026-07-17 fix(stocks): capture the settled close after market close; 0.9.4
    The 5-minute fetch tick that lands after 16:00 ET was skipped whenever
    the market was closed and quotes already existed, so the device held an
    intraday quote from up to a fetch interval before the close and never
    picked up the settled closing price.
    Add a host-tested shouldFetchStocks() that also fetches once on the
    open->closed transition. The transition state is consumed only on a
    successful commit, so a failed close fetch retries on the next tick.
    [main.cpp]
2026-07-25 revert(hardware): restore previous top-strip.stl
    [top-strip.stl]
